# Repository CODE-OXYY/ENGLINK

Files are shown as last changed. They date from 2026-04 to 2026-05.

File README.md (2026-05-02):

# ENGLINK
ENGLINK is a low cost custom designed car engine scanning solution that utilizes CAN protocol to communicate with the engine control unit of a car, it displays real time car parameters like Engine RPM, Coolant Temperature, and Vehicle Speed and display them on an onboard 1.3 inch OLED display.

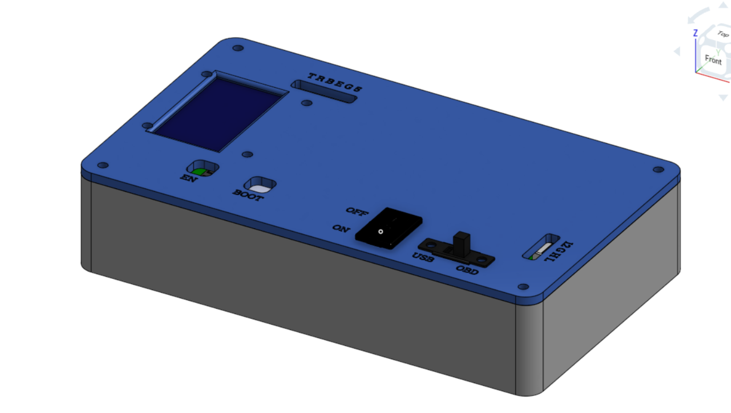
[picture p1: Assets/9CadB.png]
Cad model

*Figure: The final 3D rendered vision of the ENGLINK pocket scanner.*

---

##  Purpose
The primary objective of ENGLINK was to develop a cost effective pocket size device that can help people monitor their car health and real time data without any service center or fancy equipment. Learning CAN protocol was another objective of this project.

---

##  Hardware & PCB Design
This PCB was designed in Altium Designer.

### Schematics

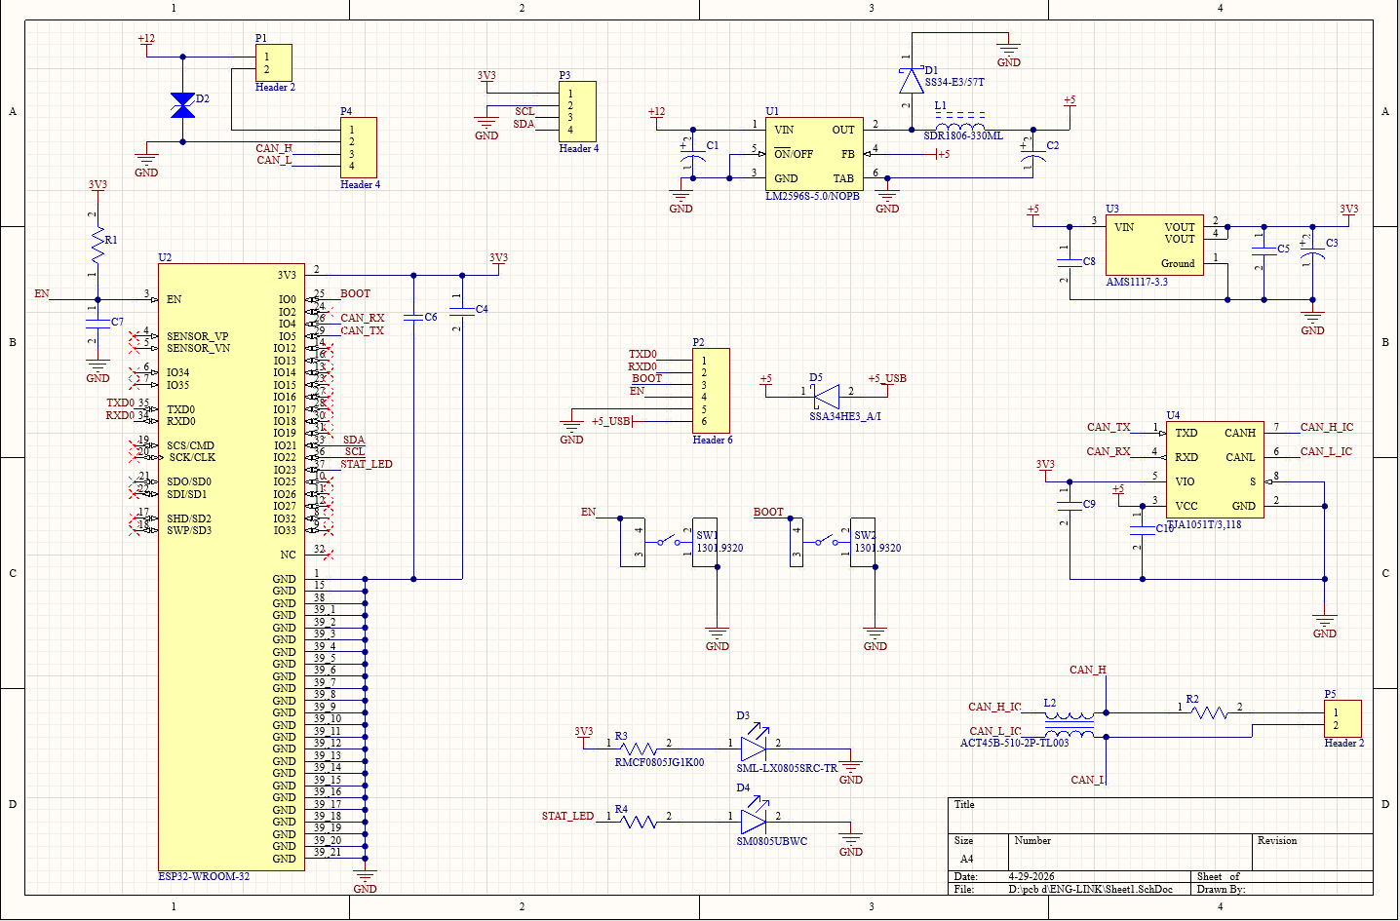
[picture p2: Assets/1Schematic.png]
Schematic

*Complete circuit design.*

### PCB Layout

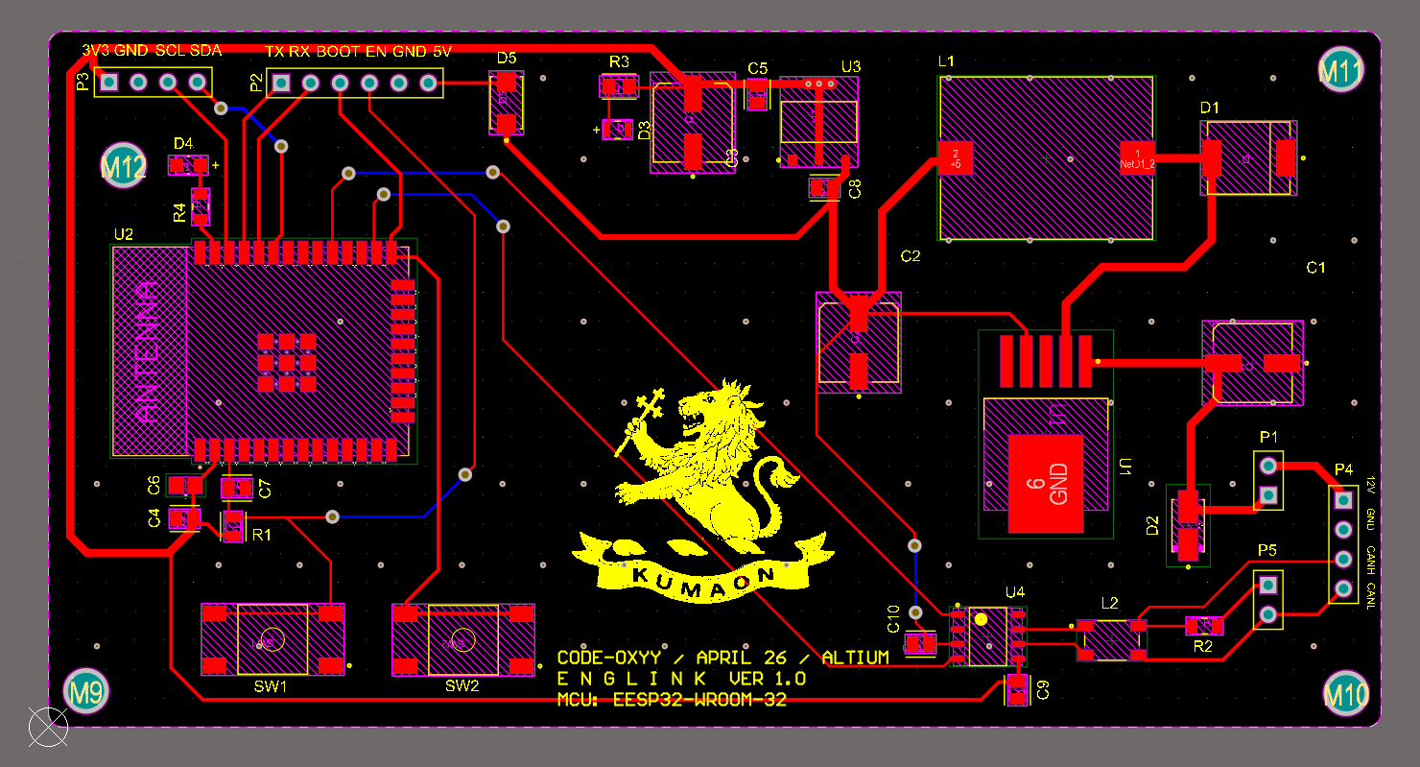
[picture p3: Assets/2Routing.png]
Routing

*PCB Layout.*

### PCB 3D View
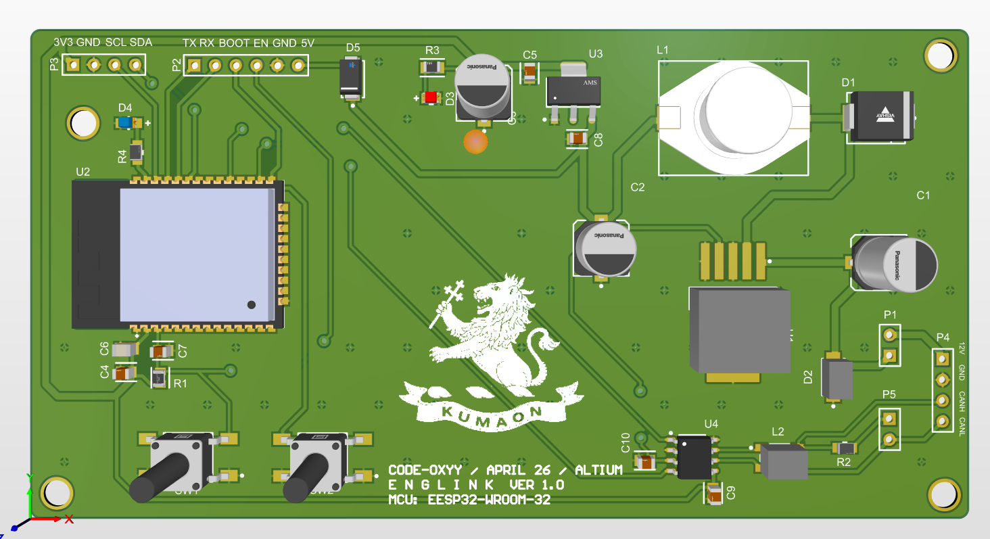
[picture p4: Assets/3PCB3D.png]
PCB 3D

*Altium's 3D visualization of the board.*

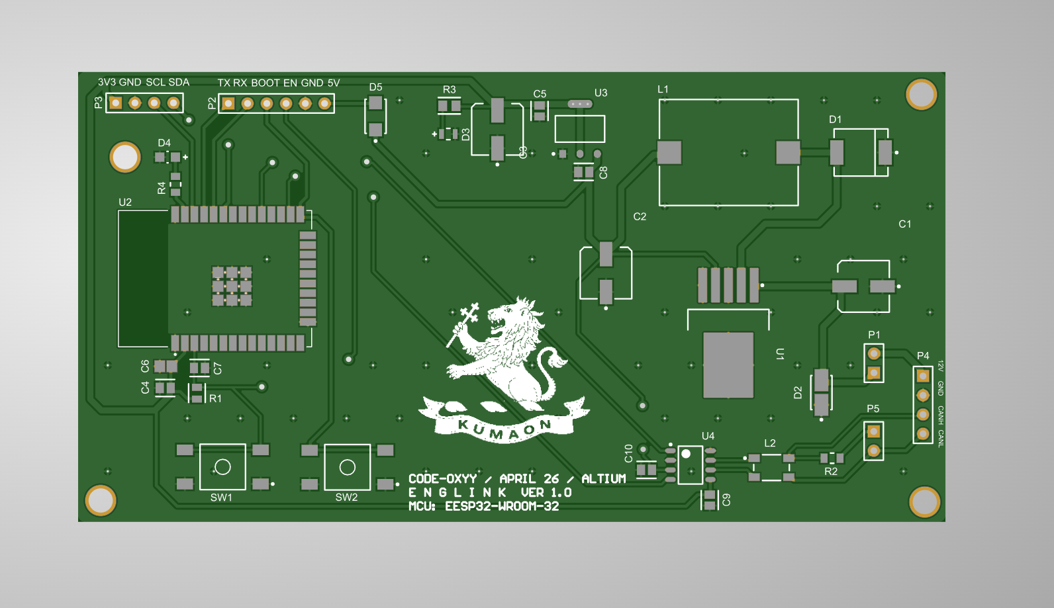
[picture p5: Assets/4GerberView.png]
Gerber View

*Final Gerber view.*

---

## Mechanical Design (Enclosure)
The custom enclosure was modeled in **Onshape** and is split into 2 main 3D printable parts.
🔗 **[View 3D Model on Onshape](https://cad.onshape.com/documents/fb16a13bf66195b204bddbb0/w/9e57cceb297baca0e2841830/e/1cae4563a1118500ba7b1aec)**

### Top Lid
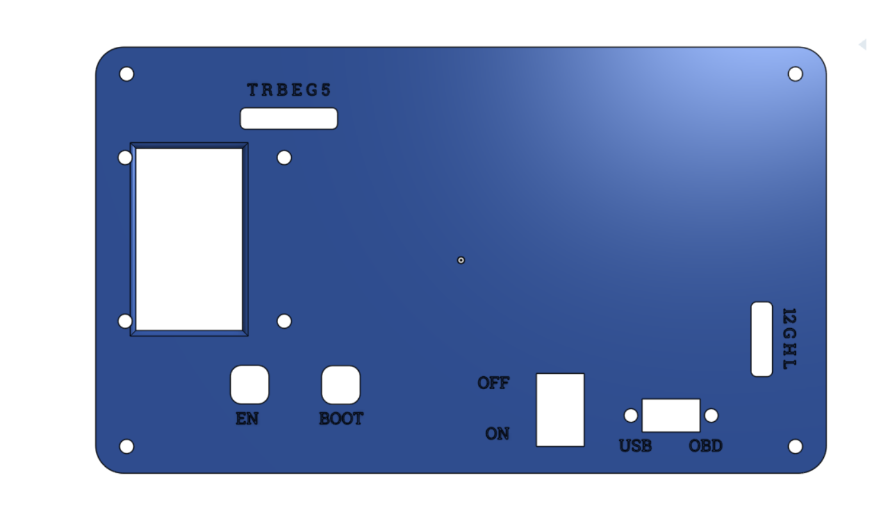
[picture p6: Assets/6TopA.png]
Top Lid A

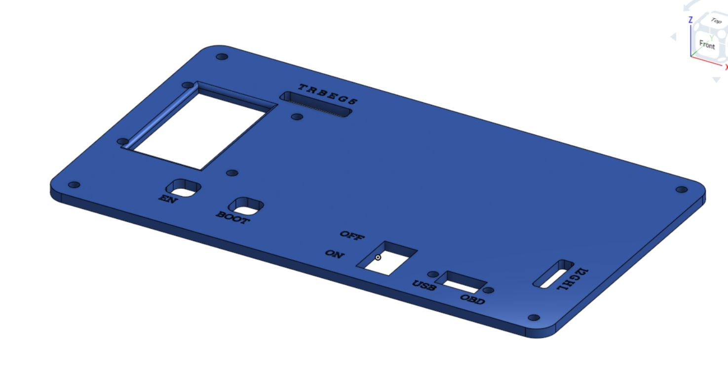
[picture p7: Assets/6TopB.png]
Top Lid B

*Top cover featuring precise cutouts for the 1.3" OLED, control switches, and neatly engraved pin labels.*

### Base
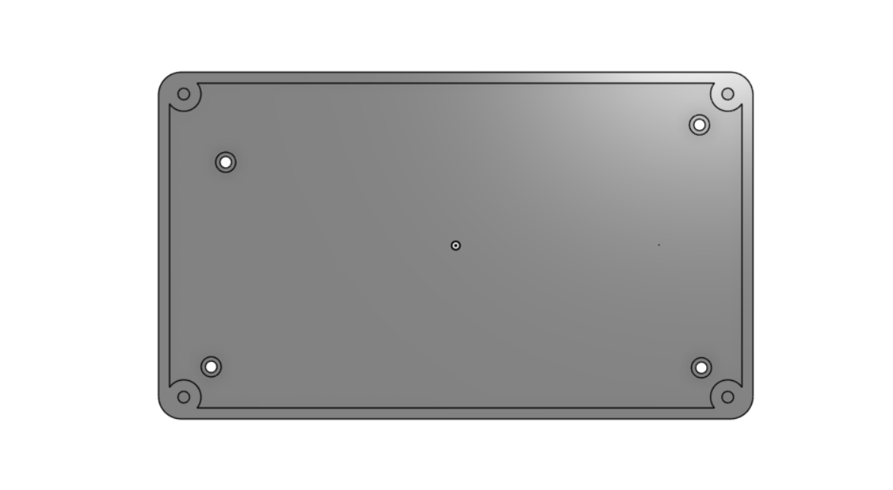
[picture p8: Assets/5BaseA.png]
Base A

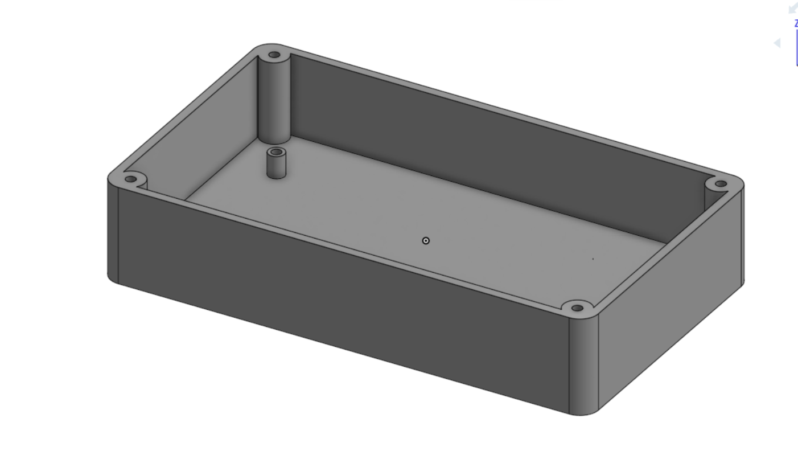
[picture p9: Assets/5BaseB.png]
Base B

*Sturdy bottom base designed with mounting standoffs to securely hold the PCB in place.*

### Assembly
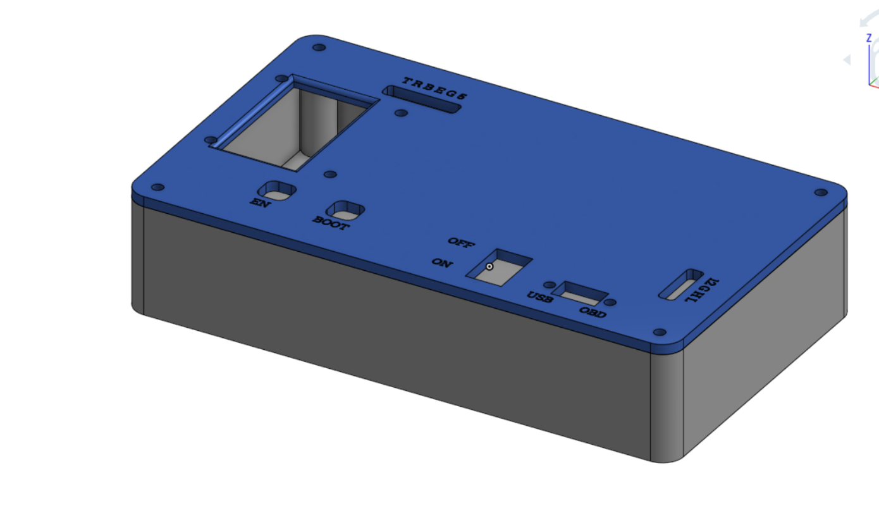
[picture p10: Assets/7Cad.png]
CAD Assembly

*CAD view showing how the top lid and bottom base sandwich together.*

### Fully Assembled ENGLINK
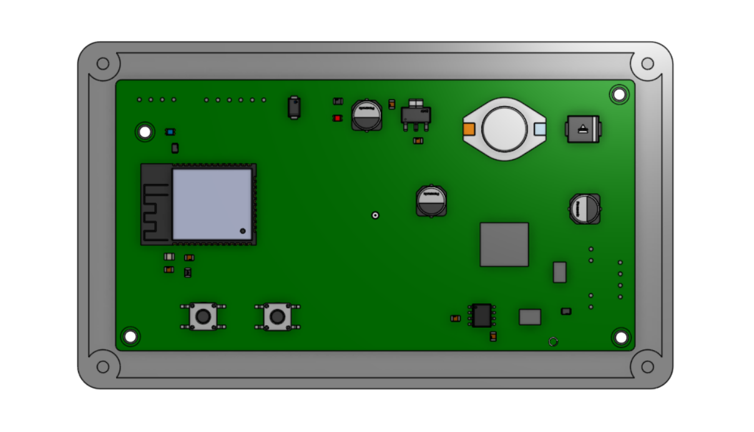
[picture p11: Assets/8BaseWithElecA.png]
Base With Elec A

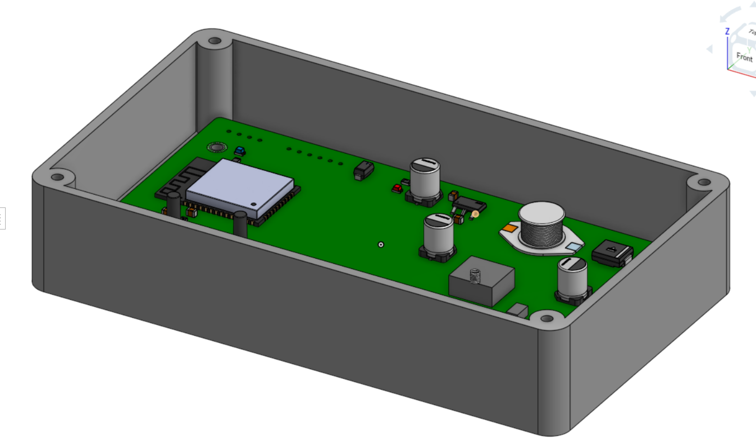
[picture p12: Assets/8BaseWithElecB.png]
Base With Elec B

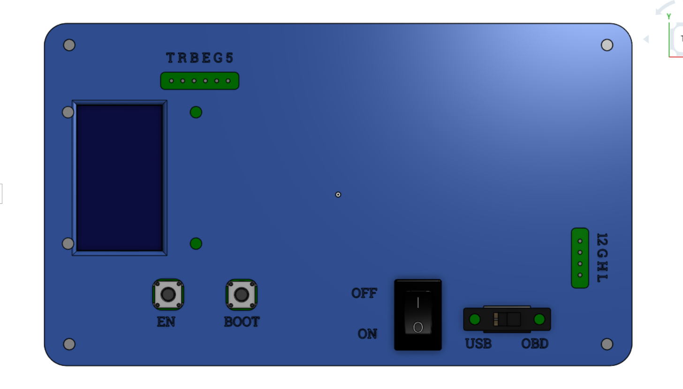
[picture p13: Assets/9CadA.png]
Final CAD A

Final CAD B
*CAD view showing how the top lid and bottom base sandwich together.*

---

## Features
* **MCU:** ESP32 WROOM 32
* **Display:** 1.3" OLED Display 
* **Communication:** On board CAN Transceiver interacting with the ESP32's native TWAI controller
* **Controls:**  * KCD11 Rocker Switch for Main Power
                 * SS12F15 Slide Switch for 120-ohm CAN Bus Termination
                 * Tactile Push Buttons for EN & BOOT (Programming)
* **Firmware:** C/C++

---

## Bill of Materials (BOM)

| Item / Part | Designator | Description / Purpose | Qty | Price | Source |
| :--- | :--- | :--- | :--- | :--- | :--- |
| ESP32-WROOM-32E | U2 | Main microcontroller  | 1 | ~$4.3 | [Electronicscomp](https://www.electronicscomp.com/espressif-esp32-wroom-32-4m-32mbit-flash-wifi-bluetooth-module) |
| 1.3" OLED Display (I2C) | - | I2C display for data viewing | 1 | ~$3.80 | [Electronicscomp](https://www.electronicscomp.com/1.3-inch-128x64-oled-display-screen-module-with-spi-serial-interface-v2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) |
| CAN Transceiver IC TJA1051T/3/1J | U4 | CAN Bus communication| 1 | ~1.70 | [Lioncircuits](https://www.lioncircuits.com/parts/TJA1051T%2F3%2F1J)|
| LM2596S-5.0 | U1 | 12V to 5V | 1 | ~$1.90 | [Robu](https://robu.in/product/lm2596s-5-0-nopb-texas-instruments-dc-dc-switching-regulator-buck-4-5v-to-40v-in-5v-out-3a-out-to-263-5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) |
| AMS1117-3.3 | U3 | 5V to 3V3 | 1 | ~$0.20 | [Robu](https://robu.in/product/ams1117-3-3-kexin-1a-fixed-3-3v-positive-electrode-18v-sot-223-4-voltage-regulators-linear-low-drop-out-ldo-regulators-rohs) |
| Bourns SDR1806 | L1 | Power Inductor | 1 | ~$0.50 | [Robu](https://robu.in/product/sdr1806-330ml-bourns-sdr1806-330ml-power-inductor-smd-33-%C2%B5h-3-a-unshielded-5-4-a-sdr1806-series) |
| SS34 SMC Diode | D1,D5 | 3A 40V Schottky Diode SMD SMC | 2 | ~$1.8 | [Lioncircuits](https://www.lioncircuits.com/parts/SS34-E3%2F57T) |
| SMAJ15CA | D2 | ESD Protection Diodes  |1 | ~$.6 | [Lioncircuits](https://www.lioncircuits.com/parts/SMAJ15CA) |
| 0805 Surface Mount LED Red | D3 | LED Red | 1 | ~$.1 | [Robu](https://robu.in/product/0805-surface-mount-led-red-50-pcs) |
| 0805 Surface Mount LED Blue | D4 |  LED Blue | 1 | ~$.1 | [Robu](https://robu.in/product/0805-surface-mount-led-blue-50-pcs) |
| 120 Ohm SMD Resistor 0805 | R2, R4 | Thick Film 0805 120 Ohm | 2 | ~$.1 | [Robu](https://robu.in/product/rc0805fr-07120rl-yageo-res-thick-film-0805-120-ohm-1-0-125w1-8w-%C2%B1100ppm-c-pad-smd-t-r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) |
| 1k Ohm SMD Resistor 0805 | R3 | Thick Film 0805 1k Ohm | 1 | ~$.1 | [Robu](https://robu.in/product/1k-ohm-1-4w-0805-surface-mount-chip-resistor-pack-of-10) |
| 10k Ohm SMD Resistor 0805 | R1 | Thick Film 0805 10k Ohm | 1 | ~$.1 | [Robu](https://robu.in/product/10k-ohm-1-8w-805-resistorreel-of-5000) |
| CL21B106KOQNFNE | C4 C5 C7 C8 C9 C10 | Samsung-Cap Ceramic 10uF 16V | 6 | ~$.1 | [Robu](https://robu.in/product/cl21b106koqnfne-samsung-cap-ceramic-10uf-16v-x7r-10-pad-smd-0805-125c-t-r) |
| 100nF 0805 SMD Capacitor | C6 | 100nF 0805 Surface Mount Multilayer Ceramic Capacitor | 1 | ~$.1 | [Robu](https://robu.in/product/100nf-0805-surface-mount-multilayer-ceramic-capacitor-pack-of-40) |
| 100uF 35V SMD Electrolytic Capacitor | C1 C2 C3 | SMD ALUMINUM ELECTROLYTIC CAPACITOR TQ 35V | 3 | ~$5 | [Robu](https://www.lioncircuits.com/parts/EEE-TQV101XAP) |
| ACT45B-510-2P-TL003 | L2 | Common-Mode Choke (CMC)  | 1 | ~$2.5 | [Lioncircuits](https://www.lioncircuits.com/parts/ACT45B-510-2P-TL003) |
| KCD11 Rocker Switch | - | Main Power control | 1 | ~$0.8 | [Rlectronicscomp](https://www.electronicscomp.com/mini-rocker-switch-6a-250v-2pin-5pcs) |
| SS12F15 Slide Switch | - | 120-ohm CAN Bus Termination | 1 | ~$0.3 | [Robu](https://robu.in/product/1-month-warranty-254) |
| Tactile Push Buttons | SW1, SW2 | EN & BOOT / Programming buttons | 1 | ~$0.30 | [Robu](https://robu.in/product/6x6x8mm-tactile-push-button-switch-pack-of-20) |
| OBD-II to Header Cable | - | Connects vehicle's OBD port to the device | 1 | ~$7.00 | [Amazon](https://www.amazon.in/Star-AutoLink-Extension-Diagnostic-STAR043/dp/B0FN4DJHJT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) |
| Custom PCB  | PCB | Main fabricated circuit board | 1 | $ 17 | [Robu](https://robu.in) |
| 3D Printed Enclosure | CASE | Top Lid & Base for housing electronics | 1 Set| - | [Printing Legion](#) |
| M3 Screws | - | For securely mounting PCB and Enclosure | 2 | ~$1.00 | [Electronicscomp](https://www.electronicscomp.com/m3-x-15mm-chhd-bolt-and-nut-set-10-pieces-pack) |
| 4 Pin 2510 Connector Kit | P4 | JST XH 2.54mm Pitch Wire-to-Board Connectors with Male & Female | 1 | $ 1.5 | [Amazon](https://www.amazon.in/Pin-2510-Connector-Wire-Board/dp/B0DXD35PCT) |
| 4 Pin Connector Kit | P3 | 4 Pin JST XH Relimate Connector (RMC) Male-Female Pair With Wire/Cable | 1 | $ .2 | [Electronicscomp](https://www.electronicscomp.com/power-supply/battery/battery-harness/4-pin-polarized-header-wire) |
| 2 Pin Connector Kit | P1 P5 | 2 Pin JST XH Relimate Connector (RMC) Male-Female Pair With Wire/Cable | 2 | $ .2 | [Electronicscomp](https://www.electronicscomp.com/2-pin-polarized-header-wire) |
| 6 Pin Connector Kit | P2 | 6 Pin JST XH Relimate Connector (RMC) Male-Female Pair With Wire/Cable | 1 | $ .2 | [Electronicscomp](https://www.electronicscomp.com/power-supply/battery/battery-harness/6-pin-polarized-header-wire) |
| FT232RL  | - | USB to TTL Serial Adapter Module | 1 | $ 1.3 | [Electronicscomp](https://www.electronicscomp.com/ft232rl-usb-ttl-serial-adaptor-module-for-arduino) |
| FLUX soldering paste  | - | Noel FLUX soldering paste | 1 | $ .5 | [Robu](https://robu.in/product/noel-flux-soldering-paste-10g) |
| Solder Wire  | - | Solder Wire 50g | 1 | $3 | [Knowledgeelectronics](https://knowledgeelectronics.com/product/solder-wire-50gm-60-40/) |

TOTAL ~ $56 

---

## 📄 License
This project is open-source and available under the **MIT License**

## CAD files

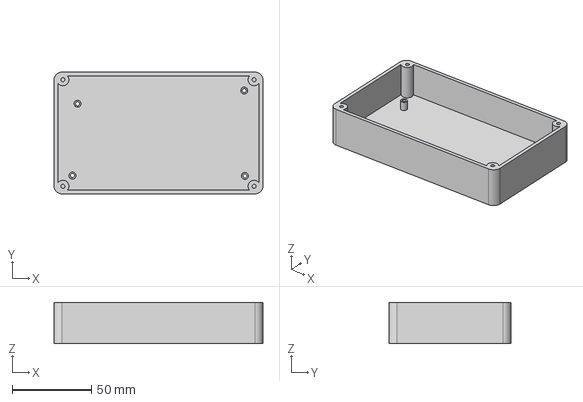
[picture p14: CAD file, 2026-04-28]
Production/ForCAD/1Base.step
131.8 x 76.8 x 26.0 mm

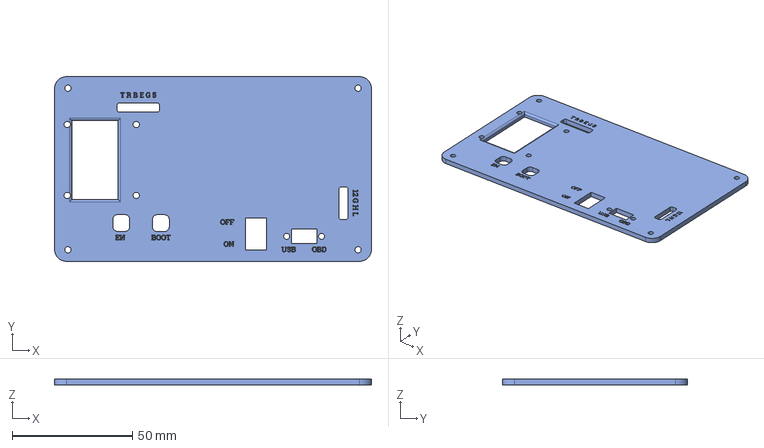
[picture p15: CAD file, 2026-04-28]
Production/ForCAD/2TopLid.step
131.8 x 76.8 x 2.40 mm

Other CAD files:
Production/ForCAD/1Base.stl
Production/ForCAD/2TopLid.stl

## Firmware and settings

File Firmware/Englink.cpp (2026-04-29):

#include <Wire.h>
#include <Adafruit_GFX.h>
#include <Adafruit_SSD1306.h>
#include "driver/twai.h"

#define SCREEN_WIDTH 128
#define SCREEN_HEIGHT 64
#define OLED_RESET -1
Adafruit_SSD1306 display(SCREEN_WIDTH, SCREEN_HEIGHT, &Wire, OLED_RESET);

#define CAN_RX_PIN GPIO_NUM_4
#define CAN_TX_PIN GPIO_NUM_5

#define OBD_BROADCAST_ID 0x7DF
#define OBD_RESPONSE_ID  0x7E8

void setup() {
  Serial.begin(115200);

  if(!display.begin(SSD1306_SWITCHCAPVCC, 0x3C)) {
    Serial.println("Display failed :(");
    while(1);
  }
  
  display.clearDisplay();
  display.setTextSize(1);
  display.setTextColor(SSD1306_WHITE);
  display.setCursor(0, 10);
  display.println("I am starting XD");
  display.display();

  twai_general_config_t g_config = TWAI_GENERAL_CONFIG_DEFAULT(CAN_TX_PIN, CAN_RX_PIN, TWAI_MODE_NORMAL);
  twai_timing_config_t t_config = TWAI_TIMING_CONFIG_500KBITS();
  twai_filter_config_t f_config = TWAI_FILTER_CONFIG_ACCEPT_ALL();

  if (twai_driver_install(&g_config, &t_config, &f_config) == ESP_OK) {
    if (twai_start() == ESP_OK) {
      display.println("CAN workingb :)");
      display.display();
    } else {
      display.println("CAN isnt working");
      display.display();
    }
  }
  delay(1000);
}

void loop() {
  twai_message_t tx_msg;
  tx_msg.identifier = OBD_BROADCAST_ID;
  tx_msg.extd = 0;
  tx_msg.data_length_code = 8;
  tx_msg.data[0] = 0x02; 
  tx_msg.data[1] = 0x01; 
  tx_msg.data[2] = 0x0C; 
  for(int i = 3; i < 8; i++) tx_msg.data[i] = 0; 

  twai_transmit(&tx_msg, pdMS_TO_TICKS(1000));

  twai_message_t rx_msg;
  if (twai_receive(&rx_msg, pdMS_TO_TICKS(200)) == ESP_OK) {
    if (rx_msg.identifier == OBD_RESPONSE_ID && rx_msg.data[2] == 0x0C) { 
      
      int rpm = ((rx_msg.data[3] * 256) + rx_msg.data[4]) / 4;
      
      display.clearDisplay();
      display.setCursor(0, 20);
      display.setTextSize(2);
      display.print("RPM: ");
      display.println(rpm);
      display.display();
      
      Serial.printf("RPM: %d\n", rpm);
    }
  }
  
  delay(100); 
}

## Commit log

2026-04-28 Added STEP files
    [1Base.step, 1Base.stl, 2TopLid.step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]
2026-04-29 Added BOM
